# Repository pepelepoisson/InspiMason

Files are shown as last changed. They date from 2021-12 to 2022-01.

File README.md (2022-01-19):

# InspiMason
***
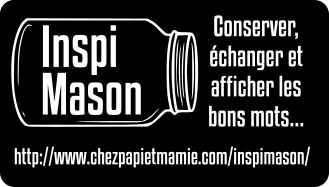
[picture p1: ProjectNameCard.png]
Project Name Card

***
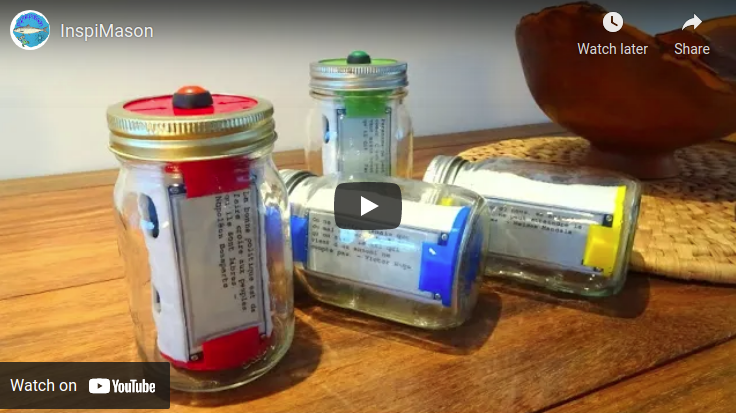
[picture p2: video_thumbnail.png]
Project video (https://youtu.be/8NvAS99MJ_w)

***
This repo contains files about a Christmas project called InspiMason. InspiMason is a small device fitted in a glass jar to save and share inspiring quotes! It used an ESP8266 brain and WiFi, a 2.9 inches waveshare epaper display, a few WS2812B RGB leds, a switch, a single cell Lipo battery and charging circuitry. Over one thousand twitter like quotations (about 160 caracters max) are stored in a text file and displyed one at a time when user presses a button. Device spends most of its time in deep sleep mode so battery can last long while the text remains on the epaper. File with quotations can be download from a [compagnon web site](http://www.chezpapietmamie.com/inspimason/) or user edited then changed by accessing the device via a web page. Can also type in a text to disply immediately on the device. All project details are available on the [project page](http://www.chezpapietmamie.com/pcube/uncategorized/inspimason/) . Do not hesitate to reach me shall you have any question or comment.
***
contact
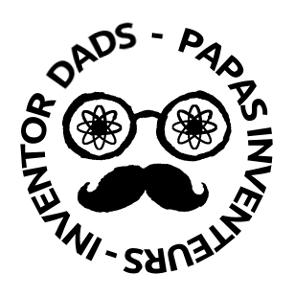
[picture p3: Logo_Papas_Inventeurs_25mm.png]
Inventor Dads logo


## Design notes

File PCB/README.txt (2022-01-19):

The PCB for this project is a reuse of a previous project WITH A CHANGE AND A CORRECTION.

REf: https://github.com/pepelepoisson/CroqueLivresSaint2021/tree/main/PCB/CroqueLivreSaintGerard2021_V1

CHANGES TO BE MADE: 
(1) Must connect WS2812B_DATA_IN to D4 (pin 11) rather than D1 (pin 14)
(2) Must connect epaper RST pin to D1 (pin 14) rather than D4 (pin 11). Failing to do this swap with create a boot problem (at least with the library/code I tried)
(3) The orientation of D1 diode is wrong on the PCB silk-screen. Must solder it in reverse!

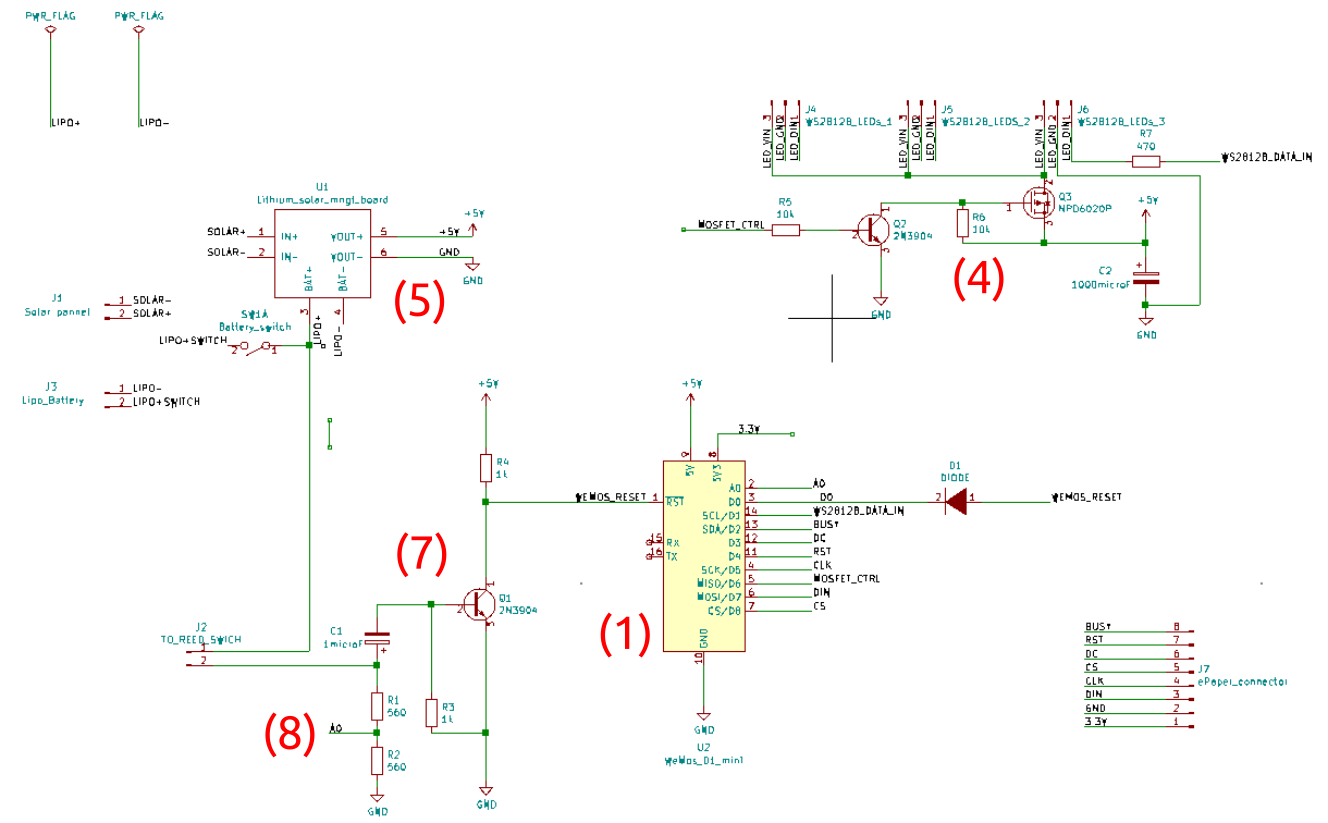
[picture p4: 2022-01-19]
PCB/flowRoot1630-7-4.png

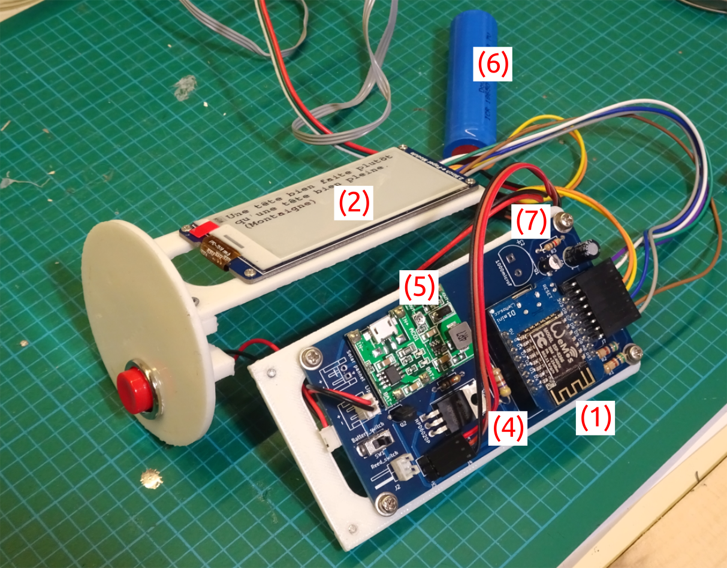
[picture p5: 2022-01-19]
PCB/PCBpic.png

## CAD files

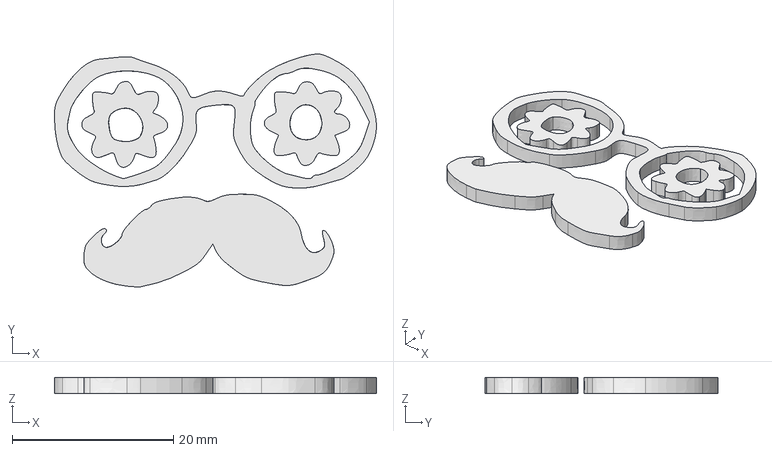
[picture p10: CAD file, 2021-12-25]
CAD/PapasInventeurs_V2.FCStd
40.0 x 28.9 x 2.00 mm

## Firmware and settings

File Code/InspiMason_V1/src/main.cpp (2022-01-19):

// InspiMason
// Check http://www.chezpapietmamie.com/inspimason/

// Main examples used to build this secondes
// Basic SPIFFS write/read example: https://github.com/G6EJD/SPIFFS-Examples/blob/master/ESP8266_SPIFFS_Example.ino
// Uploading a file to SPIFFS from browser: https://www.esp8266.com/viewtopic.php?t=5779&start=10#

// Wonderfull online true type to gfx fonts conversion tool: https://rop.nl/truetype2gfx/
// Wonderfull online tool to edit fonts: https://tchapi.github.io/Adafruit-GFX-Font-Customiser/

#include <Arduino.h>
#include <GxEPD2.h>
#include <Adafruit_GFX.h>
#include <Adafruit_I2CDevice.h>
#include <ESP8266WiFi.h>
#include <WiFiClient.h>
#include <ESP8266WebServer.h>
#include <Adafruit_NeoPixel.h>
#include <FS.h> //spiff file system
#include <ArduinoJson.h>

#define ARRAY_SIZE(A) (sizeof(A) / sizeof((A)[0]))
#define LOW_BRIGHTNESS          20
#define FRAMES_PER_SECOND   60 // 125 frames/sec <=> 8 milli/frame
#define NUM_LEDS  6
#define DATA_PIN    2    // Was 5 for GeaiRareLit
#define MOSFET_GATE  12
#define LED_ANIMATIONS_DURATION 300000 // Duration of LED animations (Milliseconds)

Adafruit_NeoPixel strip = Adafruit_NeoPixel(NUM_LEDS, DATA_PIN, NEO_GRB + NEO_KHZ800);
uint16_t brightness=LOW_BRIGHTNESS;
long start_time=0;
int code_run_counter=0;
int current_citation=0;
int number_of_citations=0;
int target_citation=0;
int code_run_counter_bkp=0;
int current_citation_bkp=0;
int number_of_citations_bkp=0;
int vbat_counter=0;
bool SetupMode=false;
bool citations_file_exists=false;
bool citation_fits=false;
bool first_time=true;
String wifi_status = "Disconnected";
String method4next = "Aleatoire";  // Warning!!!! Aucun accent sinon l'écriture dans log.json ne fonctionne plus!
String method4next_bkp = "Aleatoire";  // Warning!!!! Aucun accent sinon l'écriture dans log.json ne fonctionne plus!
String fw_version="1.0 (jan 2022)";

const int analogInPin = A0;  // ESP8266 Analog Pin ADC0 = A0
int sensorValue = 0;  // value read from the ADC0
float batteryVoltage=0;
#define batteryVoltageCalibration 165.45
#define LowBattWarningLevel 3.6
#define LowBattAlarmLevel 3.4

#define ENABLE_GxEPD2_GFX 1

#include <GxEPD2_BW.h>
#include <GxEPD2_3C.h>
#include <ModifiedFreeMonoBold9pt7b.h>
#include <Fonts/FreeMonoBold24pt7b.h>
#include "project_bitmaps128x296.h"

#define RST_PIN 0 // D3(0)
#define CS_1 SS // CS = D8(15)
#define BUSY_H_x 4 // BUSY = D2(4)

// First line = To use with GeaiRareLit epaper type and circuit
//GxEPD2_BW<GxEPD2_290_M06, GxEPD2_290_M06::HEIGHT> display1(GxEPD2_290_M06(/*CS=*/ CS_1, /*DC=D3*/ 0, /*RST=*/ -1, /*BUSY=*/ BUSY_H_x)); // GDEW029M06
// Second line = To use with waveshare 2.9 epaper - different wiring for RST pin otherwise boot problems
GxEPD2_BW<GxEPD2_290_T94, GxEPD2_290_T94::HEIGHT> display1(GxEPD2_290_T94(/*CS=D8*/ CS_1, /*DC=D3*/ 0, /*RST=D4*/ 5, /*BUSY=D2*/ BUSY_H_x)); // GDEM029T94

char* mySsid = "inspimason";
IPAddress local_ip(192,168,168,168);
IPAddress gateway(192,168,168,1);
IPAddress netmask(255,255,255,0);
String current_ip, current_ssid;
String citation;

char webpage[] PROGMEM = R"=====(
<html>
<meta charset="UTF-8">
<head>
</head>
<body>
  <form>
  <h1 style="font-size:60px;color:blue;" title="InspiMason">InspiMason - Une conserve d'idées inspirantes</h1>
    <fieldset>
    <legend style="color:blue;">Paramètres pour la connexion à un réseau WiFi existant:</legend>
      <div>
        <label for="ssid">SSID</label>
        <input value="" id="ssid" placeholder="SSID">
      </div>
      <div>
        <label for="password">PASSWORD</label>
        <input type="password" value="" id="password" placeholder="PASSWORD">
      </div>
      <div>
        <button class="primary" id="savebtn" type="button" onclick="myFunction()">SAVE</button>
      </div>
    </fieldset>
  </form>
  <form method='POST' action='/update' enctype='multipart/form-data'>
    <fieldset>
    <legend style="color:blue;">Mise à jour du fichier des citations:</legend>
      <input type='file' name='update'>
      <input type='submit' value='Update'>
    </fieldset>
    <fieldset>
    <legend style="color:blue;">Choix de l'ordre d'affichage:</legend>
    <div>
      <p> Ordre d'affichage des textes : <span id="method4next">__</span> </p>
      <button class="primary" id="togglebtn" type="button" onclick="SetDisplayOrderFunction()">Changer ordre</button>
    </div>
    </fieldset>
  </form>
  <form action="/action_page">
  <fieldset>
  <legend style="color:blue;">Message à afficher immédiatement:</legend>
    Message à envoyer:<br>
    <input type="text" name="message_web" size="150" >
    <br><br>
    <input type="submit" value="Envoyer">
    </fieldset>
  </form>
  <form>
  <fieldset>
  <legend style="color:blue;">En manque d'inspiration?</legend>
    <div>
    Consultez <a href="http://www.chezpapietmamie.com/inspimason/" target="_blank">le site web InspiMason</a> pour télecharger ou partager des fichiers de contenu!<br>
    </div>
  </fieldset>
</form>
</body>
<script>
function myFunction()
{
  console.log("button was clicked!");

  var ssid = document.getElementById("ssid").value;
  var password = document.getElementById("password").value;
  var data = {ssid:ssid, password:password};

  var xhr = new XMLHttpRequest();
  var url = "/settings";

  xhr.onreadystatechange = function() {
    if (this.readyState == 4 && this.status == 200) {
      // Typical action to be performed when the document is ready:
      if(xhr.responseText != null){
        console.log(xhr.responseText);
      }
    }
  };

  xhr.open("POST", url, true);
  xhr.send(JSON.stringify(data));
};
function SetDisplayOrderFunction()
{
  console.log("TOGGLE button was clicked!");
  var xhr = new XMLHttpRequest();
    var url = "/change_method4next";

    xhr.onreadystatechange = function() {
      if (this.readyState == 4 && this.status == 200) {
        document.getElementById("method4next").innerHTML = this.responseText;
      }
    };

    xhr.open("GET", url, true);
    xhr.send();

};

document.addEventListener('DOMContentLoaded', SetDisplayOrderFunction, false);
</script>
</html>
)=====";

char current_filename [] = "/data/citations.txt";

String filename;
ESP8266WebServer server(80);
//holds the current upload
File UploadFile;

// Add end line characters to avoid breaking words at end of lines + Substitute characters not part of 7 bit font with others that are less needed. Will be displayed properly using modified font.
String formatMessage(String message){
  // Add end line characters to avoid breaking words at end of lines
  uint16_t startpos=0;
  int messageLength=message.length();
  //Serial.println(message);
  //Serial.println(messageLength);

  // Substitute characters not part of 7 bit font with others that are less needed. Will be displayed properly using modified font.
  message.replace("ô","#");
  message.replace("É","$");
  message.replace("û","*");
  message.replace("ç","+");
  message.replace("î","<");
  message.replace("à","{");
  message.replace("ê","|");
  message.replace("é","}");
  message.replace("è","~");
  message.replace("ë",">");
  message.replace("ù","^");
  message.replace("ï","_");
  message.replace("Ê","=");
  message.replace("â","\\");
  message.replace("’","'");
  message.replace("œ","oe");


  char Buf[messageLength+1]; // Char array used to manipulate string content by position
  message.toCharArray(Buf, messageLength+1);  // Store sting content in a char array.
  citation_fits=true;

  for(uint16_t line=1; line<8; line++){
    if (messageLength-startpos>26){  // Code to run only if remaining char array length exceeds maximum size for one line with this font.
      if (line==7){
        //Serial.println("message doesn't fit on screen!");
        citation_fits=false;}
      for (uint16_t k=26; k>1;k--){   // Starting at the end of line, walk back until a space is found = begining of last word.
        if (Buf[startpos+k]==' '){  // Replace space with line break and update counter of next line start.
          Buf[startpos+k]='\n';
          startpos=startpos+k+1;
          break;
        }
      }
    }
  }

  message=Buf;
  return message;
}

// Read log.json file used to store log counters etc. If not found or corrupted then initialize counters and settings.
void read_log_data(){
  const char * _code_run_counter = "", *_current_citation = "", *_number_of_citations = "", *_method4next = "";
  const char * _code_run_counter_bkp = "", *_current_citation_bkp = "", *_number_of_citations_bkp = "", *_method4next_bkp = "";

  // Read file #1
  if(SPIFFS.exists("/log.json")){
    Serial.println("Found /log.json file");
    File logFile = SPIFFS.open("/log.json", "r");
    if(logFile){
      size_t size = logFile.size();
      std::unique_ptr<char[]> buf(new char[size]);
      logFile.readBytes(buf.get(), size);
      logFile.close();

      DynamicJsonBuffer logjsonBuffer;
      JsonObject& logjObject = logjsonBuffer.parseObject(buf.get());
      if(logjObject.success())
      {
        //Serial.println("Read values from json");
        _code_run_counter = logjObject["code_run_counter"];
        _current_citation = logjObject["current_citation"];
        _number_of_citations = logjObject["number_of_citations"];
        _method4next=logjObject["method4next"];
        if(_code_run_counter==NULL || _current_citation==NULL || _number_of_citations==NULL|| _method4next==NULL){
          Serial.println("Error retrieving stored counters - Will reset.");
          _code_run_counter = "1";
          _current_citation = "1";
          _number_of_citations="1";
          _method4next="Aleatoire";
        }
      }
    }
  }
  else {
    Serial.println("File /log.json not found - will initialize");
    _code_run_counter = "1";
    _current_citation = "1";
    _number_of_citations="1";
    _method4next="Aleatoire";
  }

  // Now repeat by reading file #2
  if(SPIFFS.exists("/log_bkp.json")){
    Serial.println("Found /log_bkp.json file");
    File logFile = SPIFFS.open("/log_bkp.json", "r");
    if(logFile){
      size_t size = logFile.size();
      std::unique_ptr<char[]> buf(new char[size]);
      logFile.readBytes(buf.get(), size);
      logFile.close();

      DynamicJsonBuffer logjsonBuffer;
      JsonObject& logjObject = logjsonBuffer.parseObject(buf.get());
      if(logjObject.success())
      {
        //Serial.println("Read values from json");
        _code_run_counter_bkp = logjObject["code_run_counter"];
        _current_citation_bkp = logjObject["current_citation"];
        _number_of_citations_bkp = logjObject["number_of_citations"];
        _method4next_bkp=logjObject["method4next"];
        if(_code_run_counter_bkp==NULL || _current_citation_bkp==NULL || _number_of_citations_bkp==NULL|| _method4next_bkp==NULL){
          Serial.println("Error retrieving stored counters - Will reset.");
          _code_run_counter_bkp = "1";
          _current_citation_bkp = "1";
          _number_of_citations_bkp="1";
          _method4next_bkp="Aleatoire";
        }
      }
    }
  }
  else {
    Serial.println("File /log_bkp.json not found - will initialize");
    _code_run_counter_bkp = "1";
    _current_citation_bkp = "1";
    _number_of_citations_bkp="1";
    _method4next_bkp="Aleatoire";
  }

  // Convert counters from char to integer.
  code_run_counter=atoi(_code_run_counter);
  current_citation=atoi(_current_citation);
  number_of_citations=atoi(_number_of_citations);
  method4next=_method4next;
  // Repeat for backup from file #2
  code_run_counter_bkp=atoi(_code_run_counter_bkp);
  current_citation_bkp=atoi(_current_citation_bkp);
  number_of_citations_bkp=atoi(_number_of_citations_bkp);
  method4next_bkp=_method4next_bkp;

  // Ensure both sets are identical otherwise use biggest values
  code_run_counter=max(code_run_counter,code_run_counter_bkp);
  current_citation=max(current_citation,current_citation_bkp);
  number_of_citations=max(number_of_citations,number_of_citations_bkp);

  String logData = "{code_run_counter:"+String(code_run_counter)+", current_citation:"+String(current_citation)+", number_of_citations:"+String(number_of_citations)+", method4next:"+method4next+"}";
  Serial.print("Got following log data: "); Serial.println(logData);
}

// Write counters and setting variables into json datalog
void update_log_data(){
  String logData = "{code_run_counter:"+String(code_run_counter)+", current_citation:"+String(current_citation)+", number_of_citations:"+String(number_of_citations)+", method4next:"+method4next+"}";
  DynamicJsonBuffer logjBuffer;
  JsonObject& logjObject = logjBuffer.parseObject(logData);
  File logFile = SPIFFS.open("/log.json", "w");
  logjObject.printTo(logFile);
  logFile.close();

  // Now repeat for backup fileName
  File logFile_bkp = SPIFFS.open("/log_bkp.json", "w");
  logjObject.printTo(logFile_bkp);
  logFile_bkp.close();

  Serial.print("Updated log data with: ");Serial.println(logData);
}

// Read citation.txt to establish the number of lines. Update number_of_citations and write to json datalog.
void ReadDataFile() {
  String NewLine;
  int number_of_lines=0;
  Serial.println("reading...");
  Serial.println("/data/" + filename);

  if (SPIFFS.exists("/data/" + filename)) {

    //SPIFFS.remove("/data/" + filename); //DEBUG
    File FileRead = SPIFFS.open("/data/" + filename, "r");
    Serial.print("output: ");
    Serial.println();
    while (FileRead.available() > 0) {
      char In = FileRead.read();
      NewLine += In;

      if (In == '\n') {
        //Serial.print(NewLine);
        // Uncoment lines below to search citation.txt to test and report lines exceeding screen size
        formatMessage(NewLine);
        if(!citation_fits){Serial.print("Line "); Serial.print(number_of_lines+1);Serial.println(" doesn't fit");}
        NewLine = "";
        number_of_lines=number_of_lines+1;
      }
    }

    FileRead.close();
    Serial.print("Number of lines in file: "); Serial.println(number_of_lines);
    if (filename=="citations.txt"){
      number_of_citations=number_of_lines;
      Serial.print("Updated number_of_citations: "); Serial.println(number_of_citations);
      current_citation=1; // Reset current_citation counter
      update_log_data();
    }
  }
}

//format bytes - Used to format file size when displaying SPIFFS file content
String formatBytes(size_t bytes){
  if (bytes < 1024){
    return String(bytes)+"B";
  } else if(bytes < (1024 * 1024)){
    return String(bytes/1024.0)+"KB";
  } else if(bytes < (1024 * 1024 * 1024)){
    return String(bytes/1024.0/1024.0)+"MB";
  } else {
    return String(bytes/1024.0/1024.0/1024.0)+"GB";
  }
}

// Print a string onto epaper display
void print_string(GxEPD2_GFX& display, String message)
{
  display1.init(115200); // enable diagnostic output on Serial
  display.setRotation(1);
  display.setFont(&FreeMonoBold9pt7b);
  display.setTextColor(GxEPD_BLACK);
  display.setFullWindow();
  display.firstPage();
  do
  {
    display.fillScreen(GxEPD_WHITE);
    display.setCursor(0, 10);
    display.println(message);
  }
  while (display.nextPage());
}

// Draw a bitmap image onto epaper
void drawTargetBitmap128x296(GxEPD2_GFX& display,uint16_t target_image){  // Call this subroutine to draw a single image referred by its position in the bitmaps array.
  display1.init(115200); // enable diagnostic output on Serial -WARNING: this disables LEDs
  display.setFullWindow();
  display.setRotation(2);
  const unsigned char* bitmaps[] = {PapasInventeursEtJeunes_128x296,ChargeBattery_128x296,InspiMasonLogoV1_128x296};
  bool m = display.mirror(true);
  display.firstPage();
  do {
    display.fillScreen(GxEPD_WHITE);
    display.drawInvertedBitmap(0, 0, bitmaps[target_image], display.epd2.WIDTH, display.epd2.HEIGHT, GxEPD_BLACK);
  }
  while (display.nextPage());
  display.mirror(m);

  // Initialise LEDs again
  pinMode(MOSFET_GATE, OUTPUT); digitalWrite(MOSFET_GATE, HIGH);
  strip.begin();
  strip.setBrightness(LOW_BRIGHTNESS);
}


// Input a value 0 to 255 to get a color value. The colours are a transition r - g - b - back to r.
uint32_t Wheel(byte WheelPos) {
  WheelPos = 255 - WheelPos;
  if(WheelPos < 85) {
    return strip.Color(255 - WheelPos * 3, 0, WheelPos * 3);
  }
  if(WheelPos < 170) {
    WheelPos -= 85;
    return strip.Color(0, WheelPos * 3, 255 - WheelPos * 3);
  }
  WheelPos -= 170;
  return strip.Color(WheelPos * 3, 255 - WheelPos * 3, 0);
}

// Set all LEDs to the same color, one after the other, with a visible delay.
void colorTransientWipe(uint32_t c) {
  for(uint16_t i=0; i<strip.numPixels(); i++) {
    strip.setPixelColor(i, c);
    strip.show();
    delay(100);
  }
}

// Set all LEDs to different colors covering a full rainbow.
void rainbowCycle() {
  uint16_t i, j;

  for(j=0; j<256; j++) {
    for(i=0; i< strip.numPixels(); i++) {
      strip.setPixelColor(i, Wheel(((i * 256 / strip.numPixels()) + j) & 255));
    }
  }
}

// Define a few LED apperns for easy use later + control of MOSFET powering LEDs.
void LED(String pattern){

  if (pattern=="deco"){
    digitalWrite(MOSFET_GATE,HIGH);
    rainbowCycle();
  }

  if (pattern=="off"){
    digitalWrite(MOSFET_GATE,LOW);
  }

  // send the 'leds' array out to the actual LED strip
  strip.show();
  // insert a delay to keep the framerate modest
  delay(1000/FRAMES_PER_SECOND);
}

// Connect to WiFi: try credentials in config.json or start as access point.
void wifiConnect()
{
  //reset networking
  WiFi.softAPdisconnect(true);
  WiFi.disconnect();
  delay(1000);
  //check for stored credentials

  if(SPIFFS.exists("/config.json")){
    Serial.println("Found /config.json file");
    const char * _ssid = "", *_pass = "";
    File configFile = SPIFFS.open("/config.json", "r");
    if(configFile){
      size_t size = configFile.size();
      std::unique_ptr<char[]> buf(new char[size]);
      configFile.readBytes(buf.get(), size);
      configFile.close();

      DynamicJsonBuffer jsonBuffer;
      JsonObject& jObject = jsonBuffer.parseObject(buf.get());
      if(jObject.success())
      {
        _ssid = jObject["ssid"];
        _pass = jObject["password"];
        Serial.println(_ssid); Serial.println(_pass);
        WiFi.mode(WIFI_STA);
        WiFi.begin(_ssid, _pass);
        unsigned long startTime = millis();
        while (WiFi.status() != WL_CONNECTED)
        {
          delay(500);
          Serial.print(".");
          if ((unsigned long)(millis() - startTime) >= 10000) break;
        }
        current_ssid=WiFi.SSID();
        current_ip=WiFi.localIP().toString();
      }
    }
  }

  if (WiFi.status() != WL_CONNECTED)
  {
    WiFi.mode(WIFI_AP);
    WiFi.softAPConfig(local_ip, gateway, netmask);
    WiFi.softAP(mySsid, NULL);  // Creating a WiFi network with no password
    Serial.println("Unable to connect to a known wifi network - Starting ESP as Access Point.");
    wifi_status="Access Point";
    current_ssid=mySsid;
    current_ip="192.168.168.168";
  }
  else {Serial.println(""); Serial.println("ESP now connected in STAtion mode to known network.");wifi_status = "Station";}
}

// Triggered by webpage when WiFi connection credentials are updated.
void handleSettingsUpdate()
{
  String data = server.arg("plain");
  DynamicJsonBuffer jBuffer;
  JsonObject& jObject = jBuffer.parseObject(data);

  File configFile = SPIFFS.open("/config.json", "w");
  jObject.printTo(configFile);
  configFile.close();

  server.send(200, "application/json", "{\"status\" : \"ok\"}");
  delay(500);

  wifiConnect();
}

// Triggered by webpage when a text message is sent to be displayed onto epaper..
void handleForm() {
 String messageWeb = server.arg("message_web");

 Serial.print("Message venu du web:");
 Serial.print("Before reformating: ");Serial.println(messageWeb);
 messageWeb=formatMessage(messageWeb);  // Modify message to replace letters not in default font and avoid breaking words at end of number_of_lines
Serial.print("After reformating: ");Serial.println(messageWeb);
 print_string(display1,messageWeb);

 //String s = "<a href='/'> Go Back </a>";
 //server.send(200, "text/html", s); //Send web page
 LED("off");
 delay(500);

 display1.powerOff();
 Serial.println("Job done! Now starting deep sleep.");
 ESP.deepSleep(0);
}
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
void loop()
{
  LED("deco");

  if (SetupMode==true){
    server.handleClient();
    delay(1);
  }

  if ((millis()-start_time>LED_ANIMATIONS_DURATION)||!SetupMode){
    LED("off");
    delay(50);


    int attempts=1;
    while ((!citation_fits)&(attempts<10)){
      Serial.println("Attempt number "+String(attempts));
      GetCitation();
      citation=formatMessage(citation);  // Modify message to avoid breaking words at end of number_of_lines
      attempts=attempts+1;
      current_citation=current_citation+1;
    }

    print_string(display1,citation);
    code_run_counter=code_run_counter+1;
    update_log_data();
    delay(500);

    display1.powerOff();
    Serial.println("Job done! Now starting deep sleep.");
    ESP.deepSleep(0);
  }
}

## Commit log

2022-01-01 Adding option to type a single message directly on web page created by the device.
2022-01-09 Added a second log.json file to inprove resilience to file corruption due to reset.
    [main.cpp]
